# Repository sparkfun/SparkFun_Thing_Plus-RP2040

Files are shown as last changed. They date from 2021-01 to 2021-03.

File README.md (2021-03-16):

SparkFun Thing Plus RP2040
========================================

SparkFun Thing Plus RP2040 (https://www.sparkfun.com/products/17745)

[*SparkFun Thing Plus RP2040 (DEV-17745)*](https://www.sparkfun.com/products/17745)

The SparkFun Thing Plus - RP2040 is a low-cost, high performance board with flexible digital interfaces featuring the Raspberry Pi Foundation's RP2040 microcontroller. Besides the Thing Plus or *Feather* footprint (with 18 GPIO pins), the board also includes an SD card slot, 16MB (128Mbit) flash memory, a JST single cell battery connector (with a charging circuit and fuel gauge sensor), an addressable WS2812 RGB LED, JTAG PTH pins, four (4-40 screw) mounting holes, and our signature Qwiic connector.

The RP2040 is supported with both C/C++ and MicroPython cross-platform development environments, including easy access to runtime debugging. It has UF2 boot and floating-point routines baked into the chip. While the chip has a large amount of internal RAM, the board includes an additional 16MB of external QSPI flash memory to store program code.

Repository Contents
-------------------

* **/Documentation** - Data sheets, additional product information
* **/Hardware** - Eagle design files (.brd, .sch)

Documentation
--------------

* **[Hookup Guide](https://learn.sparkfun.com/tutorials/1527)** - Basic hookup guide for the Thing Plus RP2040
* **[Raspberry Pi RP2040 Datasheet](https://datasheets.raspberrypi.org/rp2040/rp2040_datasheet.pdf)** - Datasheet for the RP2040
* **[SparkFun Graphical Datasheets](https://github.com/sparkfun/Graphical_Datasheets)** - Graphical datasheets for various SparkFun products.

Product Versions
----------------
* [DEV-17745](https://www.sparkfun.com/products/17745) -  initial release

License Information
-------------------

This product is _**open source**_! 

Please review the LICENSE.md file for license information. 

If you have any questions or concerns on licensing, please contact technical support on our [SparkFun forums](https://forum.sparkfun.com/viewforum.php?f=152).

Distributed as-is; no warranty is given.

- Your friends at SparkFun.

_<COLLABORATION CREDIT>_

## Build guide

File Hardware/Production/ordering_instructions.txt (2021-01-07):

panel size, 107x201mm
PCB thickness, 1.6mm
number of layers, 4
soldermask color, Red
silkscreen color, White
oz copper, 1oz
finish, HASL lead free
stencils, none
pcs per panel, 12
min trace width, 0.1270mm / 0.0050in
min drill size, 0.2000mm / 0.0079in
filename to layer stackup 1/2/3/4: GTL, GL2, GL3, GBL

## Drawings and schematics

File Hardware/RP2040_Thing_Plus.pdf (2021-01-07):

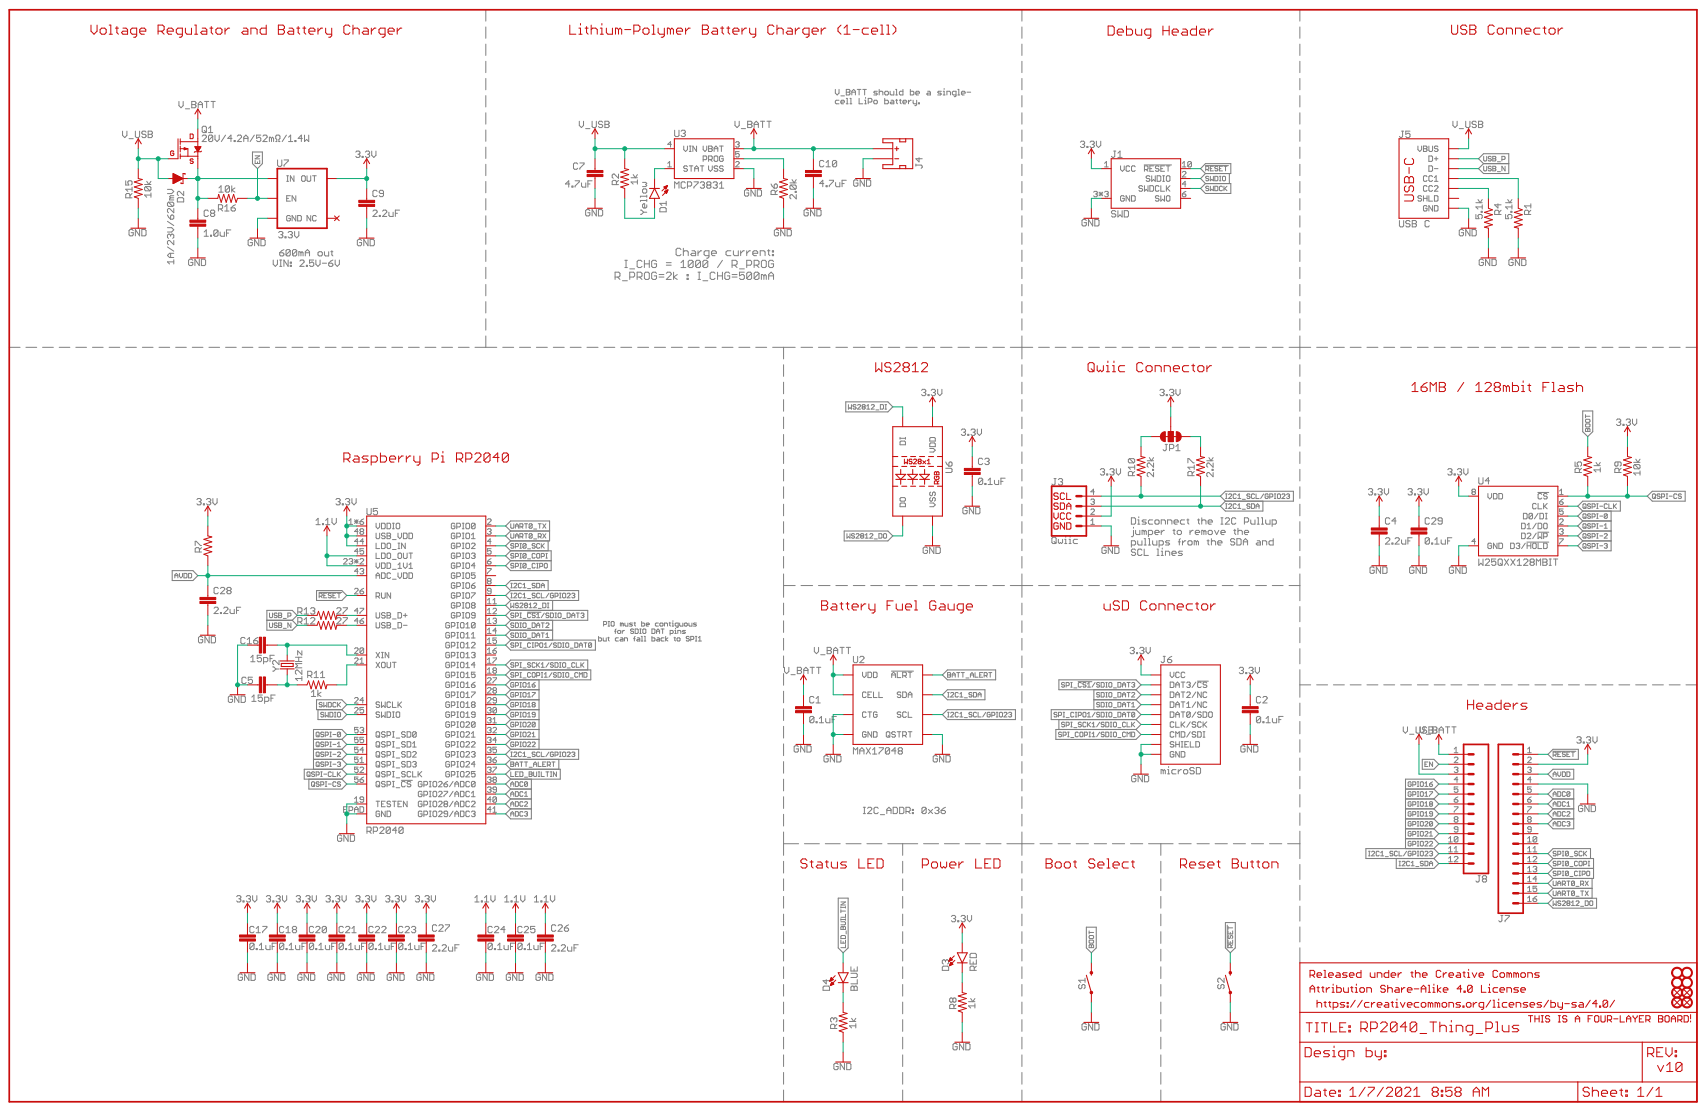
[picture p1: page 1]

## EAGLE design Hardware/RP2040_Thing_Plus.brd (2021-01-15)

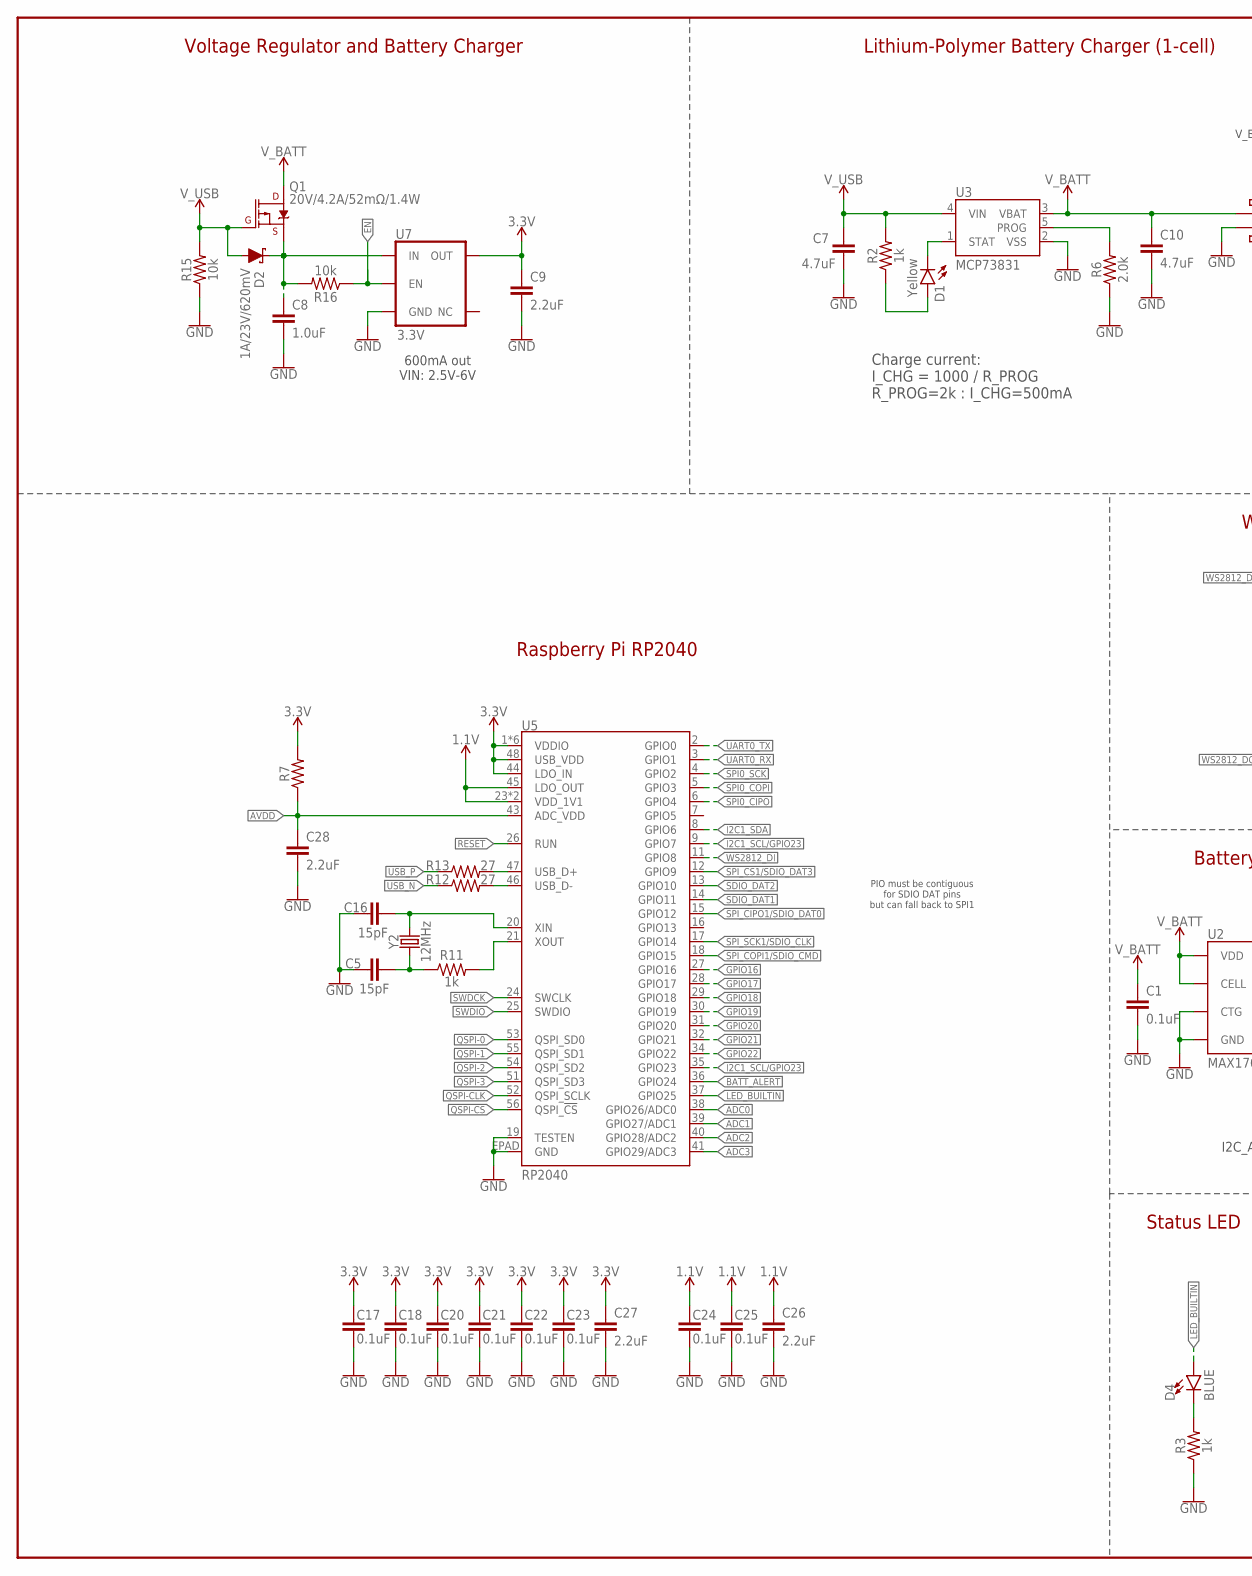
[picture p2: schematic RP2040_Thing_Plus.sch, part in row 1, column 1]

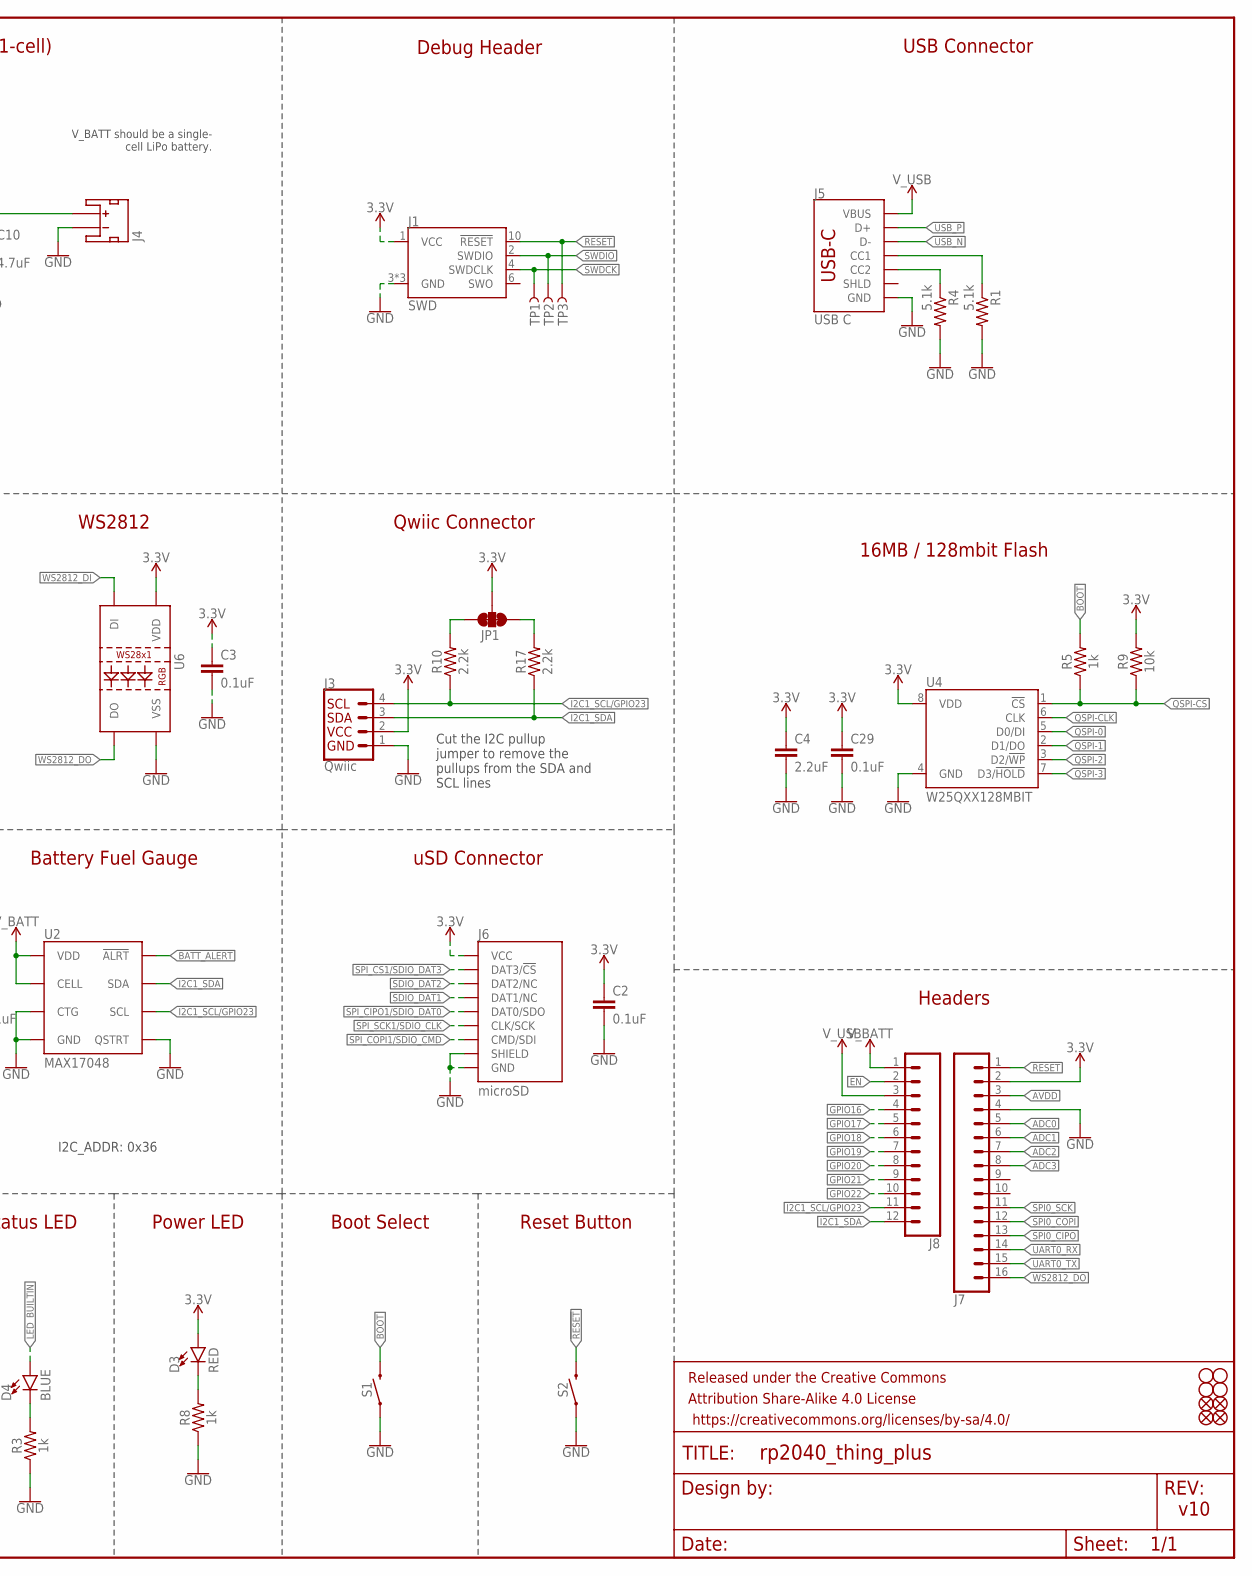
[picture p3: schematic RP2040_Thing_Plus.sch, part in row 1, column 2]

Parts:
C1, C2, C3, C17, C18, C20, C21, C22, C23, C24, C25, C29: 0.1uF; 0402-TIGHT
C4, C9, C26, C27, C28: 2.2uF; 0402-TIGHT
C5, C16: 15pF; 0402-TIGHT
C7, C10: 4.7uF; 0402-TIGHT
C8: 1.0uF; 0402-TIGHT
D1: Yellow; LED-0603
D2: 1A/23V/620mV; SOD-323
D3: RED; LED-0603
D4: BLUE; LED-0603
FD1, FD2, FD3, FD4: FIDUCIALUFIDUCIAL; FIDUCIAL-MICRO
FRAME1: FRAME-LEDGER; CREATIVE_COMMONS
H1, H2, H3, H4: STAND-OFF
J1: SWD; 2X5-PTH-1.27MM
J3: Qwiic; JST04_1MM_RA
J4: JST_2MM_MALE; JST-2-SMD
J5: USB C; USB-C-16P-4LAYER-ISOLATED
J6: microSD; MICRO-SD-SOCKET
J7: CONN_161X16_NO_SILK; 1X16_NO_SILK
J8: CONN_12NO_SILK; 1X12_NO_SILK
JP1: JUMPER-SMT_3_2-NC_TRACE_SILK; SMT-JUMPER_3_2-NC_TRACE_SILK
Q1: 20V/4.2A/52mΩ/1.4W; SOT23-3
R1, R4: 5.1k; 0402-TIGHT
R2, R3, R5, R8, R11: 1k; 0402-TIGHT
R6: 2.0k; 0603
R7: 200OHM-0402T-1/16W-1%; 0402-TIGHT
R9, R15, R16: 10k; 0402-TIGHT
R10, R17: 2.2k; 0402-TIGHT
R12, R13: 27; 0402-TIGHT
S1, S2: MOMENTARY-SWITCH-SPST-SMD-5.2MM-TALL; TACTILE_SWITCH_SMD_5.2MM
TP1, TP2, TP3: TEST-POINT3X4; PAD.03X.04
U2: MAX17048; DFN-8
U3: MCP73831; SOT23-5
U4: W25QXX128MBIT; WSON-8-6X5-SKINNY_CENTERPAD
U5: RP2040; QFN-56
U6: WS2812-2020
U7: 3.3V; SOT23-5
Y2: 12MHz; CRYSTAL-SMD-2X2.5MM

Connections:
1.1V: C24.1, C25.1, C26.1, U5.23 (VDD_1V1), U5.45 (LDO_OUT), U5.50 (VDD_1V1)
3.3V: C2.1, C3.1, C4.1, C9.1, C17.1, C18.1, C20.1, C21.1, C22.1, C23.1, C27.1, C29.1, D3.A, J1.1 (VCC), J3.2, J6.VCC, J7.2, JP1.2, R7.2, R9.2, U4.8 (VDD), U5.1 (VDDIO), U5.10 (VDDIO), U5.22 (VDDIO), U5.33 (VDDIO), U5.42 (VDDIO), U5.44 (LDO_IN), U5.48 (USB_VDD), U5.49 (VDDIO), U6.4 (VDD), U7.5 (OUT)
!RESET!: J1.10 (!RESET), J7.1, S2.3 (2), TP3.P$1, U5.26 (RUN)
ADC0: J7.5, U5.38 (GPIO26/ADC0)
ADC1: J7.6, U5.39 (GPIO27/ADC1)
ADC2: J7.7, U5.40 (GPIO28/ADC2)
ADC3: J7.8, U5.41 (GPIO29/ADC3)
AVDD: C28.1, J7.3, R7.1, U5.43 (ADC_VDD)
BATT_ALERT: U2.5 (!ALRT), U5.36 (GPIO24)
BOOT: R5.2, S1.3 (2)
EN: J8.2, R16.1, U7.3 (EN)
GND: C1.2, C2.2, C3.2, C4.2, C5.1, C7.2, C8.2, C9.2, C10.2, C16.1, C17.2, C18.2, C20.2, C21.2, C22.2, C23.2, C24.2, C25.2, C26.2, C27.2, C28.2, C29.2, J1.3 (GND), J1.5 (GND), J1.9 (GND), J3.1, J4.1 (-), J5.GND, J5.GND2 (GND), J6.CD1 (SHIELD), J6.GND, J6.GND1 (GND), J6.GND3 (GND), J7.4, R1.2, R3.1, R4.2, R6.1, R8.1, R15.1, S1.1, S2.1, U2.1 (CTG), U2.4 (GND), U2.6 (QSTRT), U2.9 (GND), U3.2 (VSS), U4.4 (GND), U5.19 (TESTEN), U5.EPAD (GND), U6.2 (VSS), U7.2 (GND)
GPIO16: J8.4, U5.27 (GPIO16)
GPIO17: J8.5, U5.28 (GPIO17)
GPIO18: J8.6, U5.29 (GPIO18)
GPIO19: J8.7, U5.30 (GPIO19)
GPIO20: J8.8, U5.31 (GPIO20)
GPIO21: J8.9, U5.32 (GPIO21)
GPIO22: J8.10, U5.34 (GPIO22)
I2C1_SCL/GPIO23: J3.4, J8.11, R10.1, U2.7 (SCL), U5.9 (GPIO7), U5.35 (GPIO23)
I2C1_SDA: J3.3, J8.12, R17.1, U2.8 (SDA), U5.8 (GPIO6)
LED_BUILTIN: D4.A, U5.37 (GPIO25)
unnamed: D4.C, R3.2
unnamed: JP1.3, R10.2
unnamed: JP1.1, R17.2
unnamed: R11.2, U5.21 (XOUT)
unnamed: C16.2, U5.20 (XIN), Y2.P3 (2)
unnamed: C5.2, R11.1, Y2.P1 (1)
unnamed: D3.C, R8.2
unnamed: D1.C, U3.1 (STAT)
unnamed: J5.A5 (CC1), R1.1
unnamed: J5.B5 (CC2), R4.1
unnamed: R6.2, U3.5 (PROG)
unnamed: C8.1, D2.C, Q1.2 (S), R16.2, U7.1 (IN)
unnamed: D1.A, R2.1
QSPI-0: U4.5 (D0/DI), U5.53 (QSPI_SD0)
QSPI-1: U4.2 (D1/DO), U5.55 (QSPI_SD1)
QSPI-2: U4.3 (D2/!WP!), U5.54 (QSPI_SD2)
QSPI-3: U4.7 (D3/!HOLD!), U5.51 (QSPI_SD3)
QSPI-CLK: U4.6 (CLK), U5.52 (QSPI_SCLK)
QSPI-CS: R5.1, R9.1, U4.1 (!CS!), U5.56 (QSPI_!CS!)
SDIO_DAT1: J6.DAT1 (DAT1/NC), U5.14 (GPIO11)
SDIO_DAT2: J6.DAT2 (DAT2/NC), U5.13 (GPIO10)
SPI0_CIPO: J7.13, U5.6 (GPIO4)
SPI0_COPI: J7.12, U5.5 (GPIO3)
SPI0_SCK: J7.11, U5.4 (GPIO2)
SPI_!CS1!/SDIO_DAT3: J6.CS/DAT3 (DAT3/!CS!), U5.12 (GPIO9)
SPI_CIPO1/SDIO_DAT0: J6.DO/DAT0 (DAT0/SDO), U5.15 (GPIO12)
SPI_COPI1/SDIO_CMD: J6.DI/CMD (CMD/SDI), U5.18 (GPIO15)
SPI_SCK1/SDIO_CLK: J6.SCLK (CLK/SCK), U5.17 (GPIO14)
SWDCK: J1.4 (SWDCLK), TP1.P$1, U5.24 (SWCLK)
SWDIO: J1.2 (SWDIO), TP2.P$1, U5.25 (SWDIO)
UART0_RX: J7.14, U5.3 (GPIO1)
UART0_TX: J7.15, U5.2 (GPIO0)
USB_F_N: R12.2, U5.46 (USB_D-)
USB_F_P: R13.2, U5.47 (USB_D+)
USB_N: J5.A7 (D-), J5.B7 (D-), R12.1
USB_P: J5.A6 (D+), J5.B6 (D+), R13.1
V_BATT: C1.1, C10.1, J4.2 (+), J8.1, Q1.3 (D), U2.2 (CELL), U2.3 (VDD), U3.3 (VBAT)
V_USB: C7.1, D2.A, J5.VBUS1 (VBUS), J5.VBUS2 (VBUS), J8.3, Q1.1 (G), R2.2, R15.2, U3.4 (VIN)
WS2812_DI: U5.11 (GPIO8), U6.3 (DI)
WS2812_DO: J7.16, U6.1 (DO)

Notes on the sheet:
V_BATT should be a single- cell LiPo battery.
Charge current: I_CHG = 1000 / R_PROG R_PROG=2k : I_CHG=500mA
Voltage Regulator and Battery Charger
Lithium-Polymer Battery Charger (1-cell)
600mA out VIN: 2.5V-6V
Reset Button
Status LED
Headers
v10
Qwiic Connector
USB Connector
Cut the I2C pullup jumper to remove the pullups from the SDA and SCL lines
Raspberry Pi RP2040
PIO must be contiguous for SDIO DAT pins but can fall back to SPI1
16MB / 128mbit Flash
uSD Connector
Battery Fuel Gauge
WS2812
I2C_ADDR: 0x36
Boot Select
Debug Header
Power LED

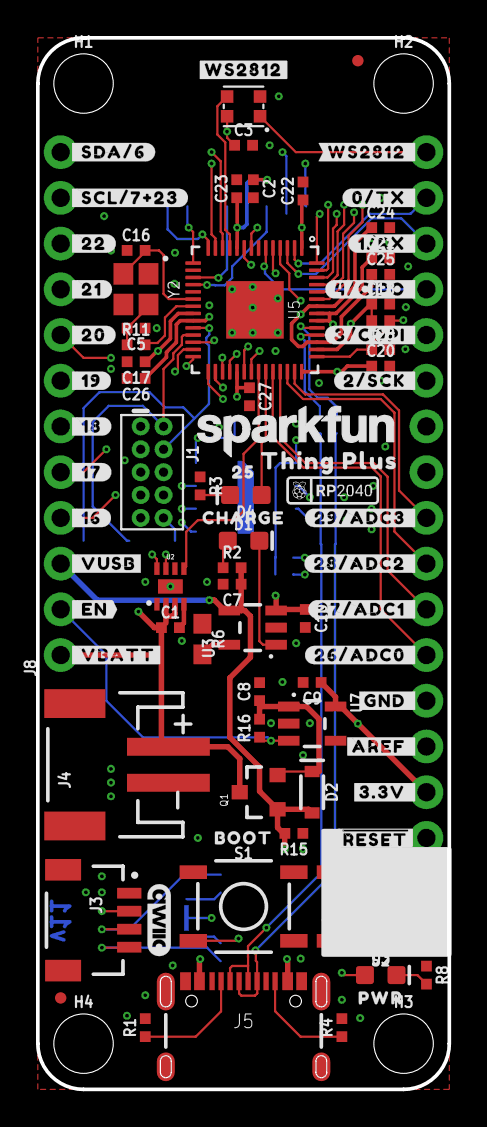
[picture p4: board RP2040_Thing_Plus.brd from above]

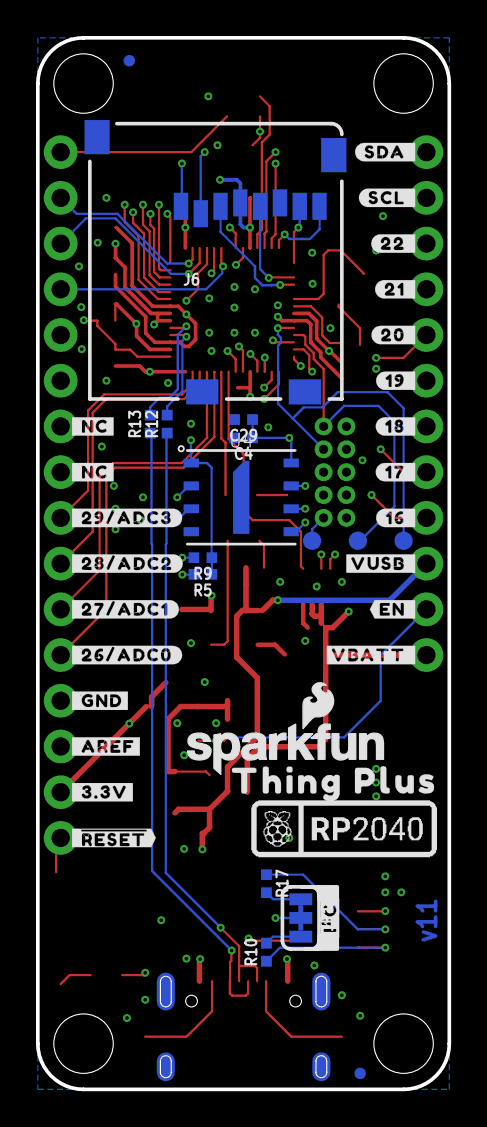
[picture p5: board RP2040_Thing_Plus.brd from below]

Board: 4 copper layers, 22.9 x 58.4 mm, 134 parts (42 on the bottom side), 62 nets.

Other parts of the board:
U$1: #_16#0
U$2: #_17#0
U$3: #_18#0
U$4: #_19#0
U$5: #_20#0
U$6: #_21#0
U$7: #_22#0
U$8: #_SCL#7#23#0
U$9: #_SDA#6#0
U$10: #WS2812_#0
U$11: #0#TX_#0
U$12: #1#RX_#0
U$13: #4#CIPO_#0
U$14: #3#COPI_#0
U$15: #2#SCK_#0
U$16: PWR0
U$17: #I�C#0
U$18: #29#ADC3_#0
U$19: #28#ADC2_#0
U$20: #27#ADC1_#0
U$21: #26#ADC0_#0
U$22: #_VUSB#0
U$23: #_EN#0
U$24: #_VBATT#0
U$25: #GND_#0
U$26: #AREF_#0
U$27: #3#3V_#0
U$28: ##RESET##0
U$29: RP2040_10
U$30: RP2040_20
U$31: ORDERING_INSTRUCTIONS
U$32: SFE_LOGO_NAME_FLAME_.1
U$33: #SCL_#0
U$34: #SDA_#0
U$35: #_#RESET##0
U$36: #_3#3V#0
U$37: #_AREF#0
U$38: #_GND#0
U$39: #_26#ADC0#0
U$40: #_27#ADC1#0
U$41: #_28#ADC2#0
U$42: #_29#ADC3#0
U$44: THING_PLUS0
U$45: SFE_LOGO_NAME_.1
U$47: THING_PLUS_0
U$54: 250
U$55: CHARGE0
U$56: BOOT0
U$57: #22_#0
U$58: #21_#0
U$59: #20_#0
U$60: #WS2812#0
U$61: #19_#0
U$62: #18_#0
U$63: #17_#0
U$64: QWIIC_4MM
U$65: #16_#0
U$66: #VUSB_#0
U$67: #EN_#0
U$68: #VBATT_#0
U$69, U$70: #_NC#0

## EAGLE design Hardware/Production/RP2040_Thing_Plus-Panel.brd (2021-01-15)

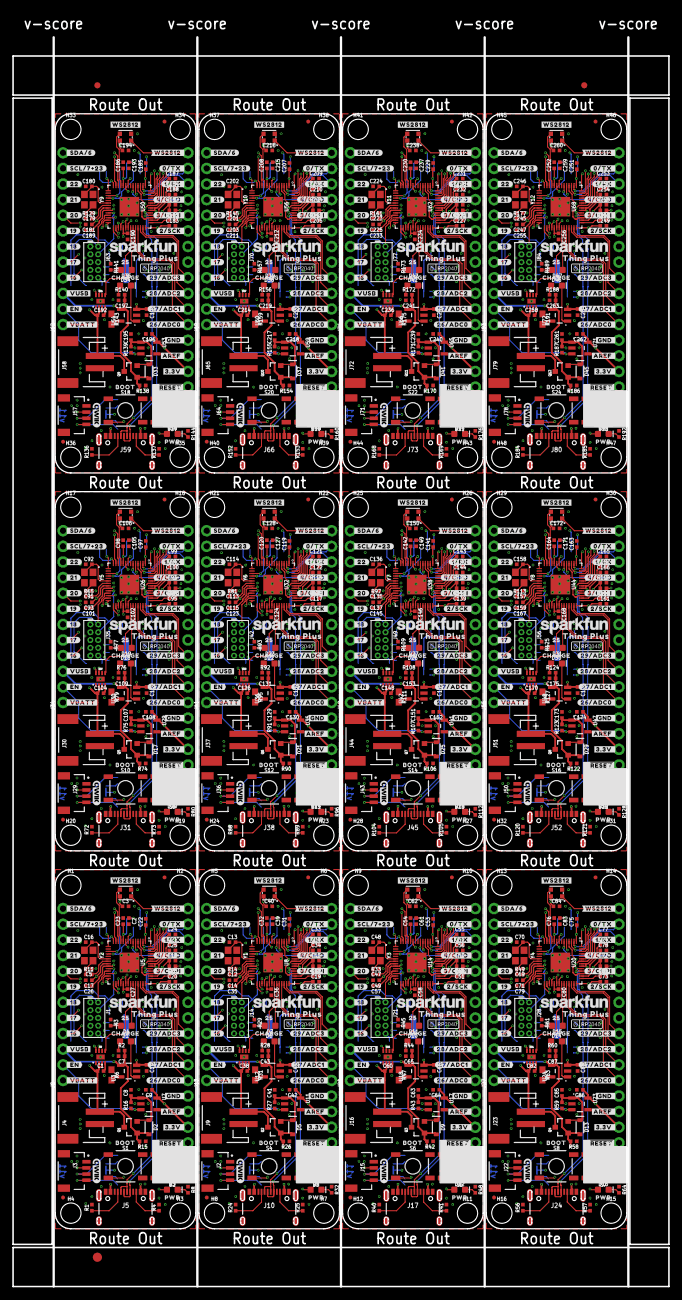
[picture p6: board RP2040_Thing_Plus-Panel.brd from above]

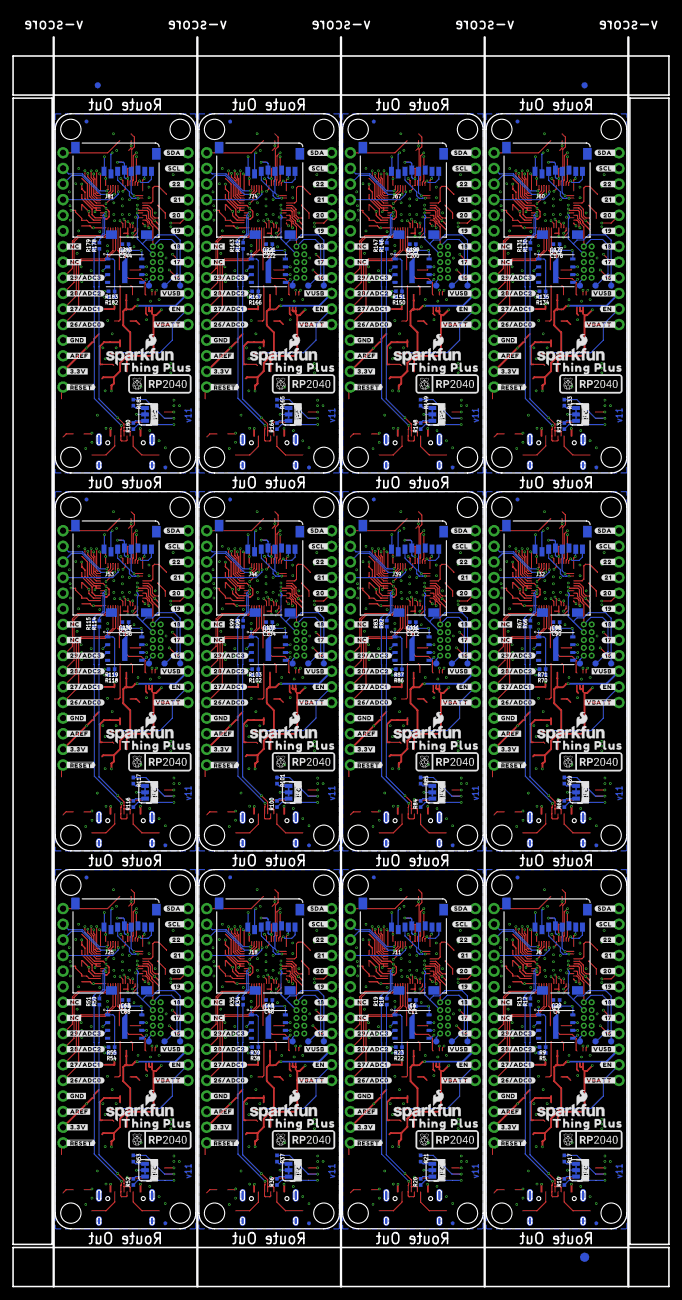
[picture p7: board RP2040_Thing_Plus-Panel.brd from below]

Board: 4 copper layers, 106.7 x 203.2 mm, 1590 parts (507 on the bottom side), 744 nets.

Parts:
C1, C2, C3, C6, C14, C15, C17, C18, C19, C20, C21, C22, C23, C24, C25, C29, C30, C31, C32, C33, C34, C38, C39, C40, C45, C49, C50, C51, C52, C53, C54, C55, C56, C60, C61, C62, C67, C71, C72, C73, C74, C75, C76, C77, C78, C82, C83, C84, C89, C93, C94, C95, C96, C97, C98, C99, C100, C104, C105, C106, C111, C115, C116, C117, C118, C119, C120, C121, C122, C126, C127, C128, C133, C137, C138, C139, C140, C141, C142, C143, C144, C148, C149, C150, C155, C159, C160, C161, C162, C163, C164, C165, C166, C170, C171, C172, C177, C181, C182, C183, C184, C185, C186, C187, C188, C192, C193, C194, C199, C203, C204, C205, C206, C207, C208, C209, C210, C214, C215, C216, C221, C225, C226, C227, C228, C229, C230, C231, C232, C236, C237, C238, C243, C247, C248, C249, C250, C251, C252, C253, C254, C258, C259, C260: 0.1uF; 0402-TIGHT
C4, C9, C11, C26, C27, C28, C35, C36, C37, C42, C46, C57, C58, C59, C64, C68, C79, C80, C81, C86, C90, C101, C102, C103, C108, C112, C123, C124, C125, C130, C134, C145, C146, C147, C152, C156, C167, C168, C169, C174, C178, C189, C190, C191, C196, C200, C211, C212, C213, C218, C222, C233, C234, C235, C240, C244, C255, C256, C257, C262: 2.2uF; 0402-TIGHT
C5, C12, C13, C16, C47, C48, C69, C70, C91, C92, C113, C114, C135, C136, C157, C158, C179, C180, C201, C202, C223, C224, C245, C246: 15pF; 0402-TIGHT
C7, C10, C43, C44, C65, C66, C87, C88, C109, C110, C131, C132, C153, C154, C175, C176, C197, C198, C219, C220, C241, C242, C263, C264: 4.7uF; 0402-TIGHT
C8, C41, C63, C85, C107, C129, C151, C173, C195, C217, C239, C261: 1.0uF; 0402-TIGHT
D1, D6, D10, D14, D18, D22, D26, D30, D34, D38, D42, D46: Yellow; LED-0603
D2, D5, D9, D13, D17, D21, D25, D29, D33, D37, D41, D45: 1A/23V/620mV; SOD-323
D3, D8, D12, D16, D20, D24, D28, D32, D36, D40, D44, D48: RED; LED-0603
D4, D7, D11, D15, D19, D23, D27, D31, D35, D39, D43, D47: BLUE; LED-0603
E$1, E$2, E$3, E$4: FIDUCIAL-1X2
E$5, E$6: FIDUCIAL-1.5X3
FD1, FD2, FD3, FD4, FD5, FD6, FD7, FD8, FD9, FD10, FD11, FD12, FD13, FD14, FD15, FD16, FD17, FD18, FD19, FD20, FD21, FD22, FD23, FD24, FD25, FD26, FD27, FD28, FD29, FD30, FD31, FD32, FD33, FD34, FD35, FD36, FD37, FD38, FD39, FD40, FD41, FD42, FD43, FD44, FD45, FD46, FD47, FD48: FIDUCIALUFIDUCIAL; FIDUCIAL-MICRO
H1, H2, H3, H4, H5, H6, H7, H8, H9, H10, H11, H12, H13, H14, H15, H16, H17, H18, H19, H20, H21, H22, H23, H24, H25, H26, H27, H28, H29, H30, H31, H32, H33, H34, H35, H36, H37, H38, H39, H40, H41, H42, H43, H44, H45, H46, H47, H48: STAND-OFF
J1, J14, J21, J28, J35, J42, J49, J56, J63, J70, J77, J84: SWD; 2X5-PTH-1.27MM
J2, J3, J15, J22, J29, J36, J43, J50, J57, J64, J71, J78: Qwiic; JST04_1MM_RA
J4, J9, J16, J23, J30, J37, J44, J51, J58, J65, J72, J79: JST-2-SMD
J5, J10, J17, J24, J31, J38, J45, J52, J59, J66, J73, J80: USB C; USB-C-16P-4LAYER-ISOLATED
J6, J11, J18, J25, J32, J39, J46, J53, J60, J67, J74, J81: microSD; MICRO-SD-SOCKET
J7, J12, J19, J26, J33, J40, J47, J54, J61, J68, J75, J82: 1X16_NO_SILK
J8, J13, J20, J27, J34, J41, J48, J55, J62, J69, J76, J83: 1X12_NO_SILK
JP1, JP2, JP3, JP4, JP5, JP6, JP7, JP8, JP9, JP10, JP11, JP12: JUMPER-SMT_3_2-NC_TRACE_SILK; SMT-JUMPER_3_2-NC_TRACE_SILK
Q1, Q2, Q3, Q4, Q5, Q6, Q7, Q8, Q9, Q10, Q11, Q12: 20V/4.2A/52mΩ/1.4W; SOT23-3
R1, R4, R24, R25, R40, R41, R56, R57, R72, R73, R88, R89, R104, R105, R120, R121, R136, R137, R152, R153, R168, R169, R184, R185: 5.1k; 0402-TIGHT
R2, R3, R5, R8, R11, R14, R22, R28, R29, R32, R33, R38, R44, R45, R48, R49, R54, R60, R61, R64, R65, R70, R76, R77, R80, R81, R86, R92, R93, R96, R97, R102, R108, R109, R112, R113, R118, R124, R125, R128, R129, R134, R140, R141, R144, R145, R150, R156, R157, R160, R161, R166, R172, R173, R176, R177, R182, R188, R189, R192: 1k; 0402-TIGHT
R6, R31, R47, R63, R79, R95, R111, R127, R143, R159, R175, R191: 2.0k; 0603
R7, R30, R46, R62, R78, R94, R110, R126, R142, R158, R174, R190: 200OHM-0402T-1/16W-1%; 0402-TIGHT
R9, R15, R16, R23, R26, R27, R39, R42, R43, R55, R58, R59, R71, R74, R75, R87, R90, R91, R103, R106, R107, R119, R122, R123, R135, R138, R139, R151, R154, R155, R167, R170, R171, R183, R186, R187: 10k; 0402-TIGHT
R10, R17, R20, R21, R36, R37, R52, R53, R68, R69, R84, R85, R100, R101, R116, R117, R132, R133, R148, R149, R164, R165, R180, R181: 2.2k; 0402-TIGHT
R12, R13, R18, R19, R34, R35, R50, R51, R66, R67, R82, R83, R98, R99, R114, R115, R130, R131, R146, R147, R162, R163, R178, R179: 27; 0402-TIGHT
S1, S2, S3, S4, S5, S6, S7, S8, S9, S10, S11, S12, S13, S14, S15, S16, S17, S18, S19, S20, S21, S22, S23, S24: MOMENTARY-SWITCH-SPST-SMD-5.2MM-TALL; TACTILE_SWITCH_SMD_5.2MM
TP1, TP2, TP3, TP4, TP5, TP6, TP7, TP8, TP9, TP10, TP11, TP12, TP13, TP14, TP15, TP16, TP17, TP18, TP19, TP20, TP21, TP22, TP23, TP24, TP25, TP26, TP27, TP28, TP29, TP30, TP31, TP32, TP33, TP34, TP35, TP36: PAD.03X.04
U1, U4, U13, U19, U25, U31, U37, U43, U49, U55, U61, U67: W25QXX128MBIT; WSON-8-6X5-SKINNY_CENTERPAD
U2, U9, U15, U21, U27, U33, U39, U45, U51, U57, U63, U69: MAX17048; DFN-8
U3, U12, U18, U24, U30, U36, U42, U48, U54, U60, U66, U72: MCP73831; SOT23-5
U5, U8, U14, U20, U26, U32, U38, U44, U50, U56, U62, U68: RP2040; QFN-56
U6, U10, U16, U22, U28, U34, U40, U46, U52, U58, U64, U70: WS2812-2020
U7, U11, U17, U23, U29, U35, U41, U47, U53, U59, U65, U71: 3.3V; SOT23-5
U$1, U$31, U$123, U$184, U$245, U$306, U$367, U$428, U$489, U$550, U$611, U$672: #_16#0
U$2, U$43, U$124, U$185, U$246, U$307, U$368, U$429, U$490, U$551, U$612, U$673: #_17#0
U$3, U$46, U$125, U$186, U$247, U$308, U$369, U$430, U$491, U$552, U$613, U$674: #_18#0
U$4, U$48, U$126, U$187, U$248, U$309, U$370, U$431, U$492, U$553, U$614, U$675: #_19#0
U$5, U$49, U$127, U$188, U$249, U$310, U$371, U$432, U$493, U$554, U$615, U$676: #_20#0
U$6, U$50, U$128, U$189, U$250, U$311, U$372, U$433, U$494, U$555, U$616, U$677: #_21#0
U$7, U$51, U$129, U$190, U$251, U$312, U$373, U$434, U$495, U$556, U$617, U$678: #_22#0
U$8, U$75, U$136, U$197, U$258, U$319, U$380, U$441, U$502, U$563, U$624, U$685: #_SCL#7#23#0
U$9, U$76, U$137, U$198, U$259, U$320, U$381, U$442, U$503, U$564, U$625, U$686: #_SDA#6#0
U$10, U$52, U$130, U$191, U$252, U$313, U$374, U$435, U$496, U$557, U$618, U$679: #WS2812_#0
U$11, U$53, U$131, U$192, U$253, U$314, U$375, U$436, U$497, U$558, U$619, U$680: #0#TX_#0
U$12, U$71, U$132, U$193, U$254, U$315, U$376, U$437, U$498, U$559, U$620, U$681: #1#RX_#0
U$13, U$72, U$133, U$194, U$255, U$316, U$377, U$438, U$499, U$560, U$621, U$682: #4#CIPO_#0
U$14, U$73, U$134, U$195, U$256, U$317, U$378, U$439, U$500, U$561, U$622, U$683: #3#COPI_#0
U$15, U$74, U$135, U$196, U$257, U$318, U$379, U$440, U$501, U$562, U$623, U$684: #2#SCK_#0
U$16, U$116, U$177, U$238, U$299, U$360, U$421, U$482, U$543, U$604, U$665, U$726: PWR0
U$17, U$117, U$178, U$239, U$300, U$361, U$422, U$483, U$544, U$605, U$666, U$727: #I�C#0
U$18, U$77, U$138, U$199, U$260, U$321, U$382, U$443, U$504, U$565, U$626, U$687: #29#ADC3_#0
U$19, U$78, U$139, U$200, U$261, U$322, U$383, U$444, U$505, U$566, U$627, U$688: #28#ADC2_#0
U$20, U$79, U$140, U$201, U$262, U$323, U$384, U$445, U$506, U$567, U$628, U$689: #27#ADC1_#0
U$21, U$80, U$141, U$202, U$263, U$324, U$385, U$446, U$507, U$568, U$629, U$690: #26#ADC0_#0
U$22, U$81, U$142, U$203, U$264, U$325, U$386, U$447, U$508, U$569, U$630, U$691: #_VUSB#0
U$23, U$82, U$143, U$204, U$265, U$326, U$387, U$448, U$509, U$570, U$631, U$692: #_EN#0
U$24, U$83, U$144, U$205, U$266, U$327, U$388, U$449, U$510, U$571, U$632, U$693: #_VBATT#0
U$25, U$84, U$145, U$206, U$267, U$328, U$389, U$450, U$511, U$572, U$633, U$694: #GND_#0
U$26, U$85, U$146, U$207, U$268, U$329, U$390, U$451, U$512, U$573, U$634, U$695: #AREF_#0
U$27, U$86, U$147, U$208, U$269, U$330, U$391, U$452, U$513, U$574, U$635, U$696: #3#3V_#0
U$28, U$87, U$148, U$209, U$270, U$331, U$392, U$453, U$514, U$575, U$636, U$697: ##RESET##0
U$29, U$122, U$183, U$244, U$305, U$366, U$427, U$488, U$549, U$610, U$671, U$732: RP2040_10
U$30, U$121, U$182, U$243, U$304, U$365, U$426, U$487, U$548, U$609, U$670, U$731: RP2040_20
U$32, U$90, U$151, U$212, U$273, U$334, U$395, U$456, U$517, U$578, U$639, U$700: SFE_LOGO_NAME_FLAME_.1
U$33, U$104, U$165, U$226, U$287, U$348, U$409, U$470, U$531, U$592, U$653, U$714: #SCL_#0
U$34, U$105, U$166, U$227, U$288, U$349, U$410, U$471, U$532, U$593, U$654, U$715: #SDA_#0
U$35, U$106, U$167, U$228, U$289, U$350, U$411, U$472, U$533, U$594, U$655, U$716: #_#RESET##0
U$36, U$107, U$168, U$229, U$290, U$351, U$412, U$473, U$534, U$595, U$656, U$717: #_3#3V#0
U$37, U$108, U$169, U$230, U$291, U$352, U$413, U$474, U$535, U$596, U$657, U$718: #_AREF#0
U$38, U$109, U$170, U$231, U$292, U$353, U$414, U$475, U$536, U$597, U$658, U$719: #_GND#0
U$39, U$110, U$171, U$232, U$293, U$354, U$415, U$476, U$537, U$598, U$659, U$720: #_26#ADC0#0
U$40, U$111, U$172, U$233, U$294, U$355, U$416, U$477, U$538, U$599, U$660, U$721: #_27#ADC1#0
U$41, U$112, U$173, U$234, U$295, U$356, U$417, U$478, U$539, U$600, U$661, U$722: #_28#ADC2#0
U$42, U$113, U$174, U$235, U$296, U$357, U$418, U$479, U$540, U$601, U$662, U$723: #_29#ADC3#0
U$44, U$120, U$181, U$242, U$303, U$364, U$425, U$486, U$547, U$608, U$669, U$730: THING_PLUS0
U$45, U$118, U$179, U$240, U$301, U$362, U$423, U$484, U$545, U$606, U$667, U$728: SFE_LOGO_NAME_.1
U$47, U$119, U$180, U$241, U$302, U$363, U$424, U$485, U$546, U$607, U$668, U$729: THING_PLUS_0
U$54, U$91, U$152, U$213, U$274, U$335, U$396, U$457, U$518, U$579, U$640, U$701: 250
U$55, U$92, U$153, U$214, U$275, U$336, U$397, U$458, U$519, U$580, U$641, U$702: CHARGE0
U$56, U$93, U$154, U$215, U$276, U$337, U$398, U$459, U$520, U$581, U$642, U$703: BOOT0
U$57, U$94, U$155, U$216, U$277, U$338, U$399, U$460, U$521, U$582, U$643, U$704: #22_#0
U$58, U$95, U$156, U$217, U$278, U$339, U$400, U$461, U$522, U$583, U$644, U$705: #21_#0
U$59, U$96, U$157, U$218, U$279, U$340, U$401, U$462, U$523, U$584, U$645, U$706: #20_#0
U$60, U$88, U$149, U$210, U$271, U$332, U$393, U$454, U$515, U$576, U$637, U$698: #WS2812#0
U$61, U$97, U$158, U$219, U$280, U$341, U$402, U$463, U$524, U$585, U$646, U$707: #19_#0
U$62, U$98, U$159, U$220, U$281, U$342, U$403, U$464, U$525, U$586, U$647, U$708: #18_#0
U$63, U$99, U$160, U$221, U$282, U$343, U$404, U$465, U$526, U$587, U$648, U$709: #17_#0
U$64, U$89, U$150, U$211, U$272, U$333, U$394, U$455, U$516, U$577, U$638, U$699: QWIIC_4MM
U$65, U$100, U$161, U$222, U$283, U$344, U$405, U$466, U$527, U$588, U$649, U$710: #16_#0
U$66, U$101, U$162, U$223, U$284, U$345, U$406, U$467, U$528, U$589, U$650, U$711: #VUSB_#0
U$67, U$102, U$163, U$224, U$285, U$346, U$407, U$468, U$529, U$590, U$651, U$712: #EN_#0
U$68, U$103, U$164, U$225, U$286, U$347, U$408, U$469, U$530, U$591, U$652, U$713: #VBATT_#0
U$69, U$70, U$114, U$115, U$175, U$176, U$236, U$237, U$297, U$298, U$358, U$359, U$419, U$420, U$480, U$481, U$541, U$542, U$602, U$603, U$663, U$664, U$724, U$725: #_NC#0
Y1, Y2, Y3, Y4, Y5, Y6, Y7, Y8, Y9, Y10, Y11, Y12: 12MHz; CRYSTAL-SMD-2X2.5MM

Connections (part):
1.1V: C24.1, C25.1, C26.1, U5.23, U5.45, U5.50
1.1V1: C33.1, C34.1, C35.1, U8.23, U8.45, U8.50
1.1V2: C55.1, C56.1, C57.1, U14.23, U14.45, U14.50
1.1V3: C77.1, C78.1, C79.1, U20.23, U20.45, U20.50
1.1V4: C99.1, C100.1, C101.1, U26.23, U26.45, U26.50
1.1V5: C121.1, C122.1, C123.1, U32.23, U32.45, U32.50
1.1V6: C143.1, C144.1, C145.1, U38.23, U38.45, U38.50
1.1V7: C165.1, C166.1, C167.1, U44.23, U44.45, U44.50
1.1V8: C187.1, C188.1, C189.1, U50.23, U50.45, U50.50
1.1V9: C209.1, C210.1, C211.1, U56.23, U56.45, U56.50
1.1V10: C231.1, C232.1, C233.1, U62.23, U62.45, U62.50
1.1V11: C253.1, C254.1, C255.1, U68.23, U68.45, U68.50
3.3V: C2.1, C3.1, C4.1, C9.1, C17.1, C18.1, C20.1, C21.1, C22.1, C23.1, C27.1, C29.1, D3.A, J1.1, J3.2, J6.VCC, J7.2, JP1.2, R7.2, R9.2, U4.8, U5.1, U5.10, U5.22, U5.33, U5.42, U5.44, U5.48, U5.49, U6.4, U7.5
3.3V1: C6.1, C11.1, C14.1, C15.1, C19.1, C30.1, C31.1, C32.1, C36.1, C39.1, C40.1, C42.1, D8.A, J2.2, J11.VCC, J12.2, J14.1, JP2.2, R23.2, R30.2, U1.8, U8.1, U8.10, U8.22, U8.33, U8.42, U8.44, U8.48, U8.49, U10.4, U11.5
3.3V2: C45.1, C46.1, C49.1, C50.1, C51.1, C52.1, C53.1, C54.1, C58.1, C61.1, C62.1, C64.1, D12.A, J15.2, J18.VCC, J19.2, J21.1, JP3.2, R39.2, R46.2, U13.8, U14.1, U14.10, U14.22, U14.33, U14.42, U14.44, U14.48, U14.49, U16.4, U17.5
3.3V3: C67.1, C68.1, C71.1, C72.1, C73.1, C74.1, C75.1, C76.1, C80.1, C83.1, C84.1, C86.1, D16.A, J22.2, J25.VCC, J26.2, J28.1, JP4.2, R55.2, R62.2, U19.8, U20.1, U20.10, U20.22, U20.33, U20.42, U20.44, U20.48, U20.49, U22.4, U23.5
3.3V4: C89.1, C90.1, C93.1, C94.1, C95.1, C96.1, C97.1, C98.1, C102.1, C105.1, C106.1, C108.1, D20.A, J29.2, J32.VCC, J33.2, J35.1, JP5.2, R71.2, R78.2, U25.8, U26.1, U26.10, U26.22, U26.33, U26.42, U26.44, U26.48, U26.49, U28.4, U29.5
3.3V5: C111.1, C112.1, C115.1, C116.1, C117.1, C118.1, C119.1, C120.1, C124.1, C127.1, C128.1, C130.1, D24.A, J36.2, J39.VCC, J40.2, J42.1, JP6.2, R87.2, R94.2, U31.8, U32.1, U32.10, U32.22, U32.33, U32.42, U32.44, U32.48, U32.49, U34.4, U35.5
3.3V6: C133.1, C134.1, C137.1, C138.1, C139.1, C140.1, C141.1, C142.1, C146.1, C149.1, C150.1, C152.1, D28.A, J43.2, J46.VCC, J47.2, J49.1, JP7.2, R103.2, R110.2, U37.8, U38.1, U38.10, U38.22, U38.33, U38.42, U38.44, U38.48, U38.49, U40.4, U41.5
3.3V7: C155.1, C156.1, C159.1, C160.1, C161.1, C162.1, C163.1, C164.1, C168.1, C171.1, C172.1, C174.1, D32.A, J50.2, J53.VCC, J54.2, J56.1, JP8.2, R119.2, R126.2, U43.8, U44.1, U44.10, U44.22, U44.33, U44.42, U44.44, U44.48, U44.49, U46.4, U47.5
3.3V8: C177.1, C178.1, C181.1, C182.1, C183.1, C184.1, C185.1, C186.1, C190.1, C193.1, C194.1, C196.1, D36.A, J57.2, J60.VCC, J61.2, J63.1, JP9.2, R135.2, R142.2, U49.8, U50.1, U50.10, U50.22, U50.33, U50.42, U50.44, U50.48, U50.49, U52.4, U53.5
3.3V9: C199.1, C200.1, C203.1, C204.1, C205.1, C206.1, C207.1, C208.1, C212.1, C215.1, C216.1, C218.1, D40.A, J64.2, J67.VCC, J68.2, J70.1, JP10.2, R151.2, R158.2, U55.8, U56.1, U56.10, U56.22, U56.33, U56.42, U56.44, U56.48, U56.49, U58.4, U59.5
3.3V10: C221.1, C222.1, C225.1, C226.1, C227.1, C228.1, C229.1, C230.1, C234.1, C237.1, C238.1, C240.1, D44.A, J71.2, J74.VCC, J75.2, J77.1, JP11.2, R167.2, R174.2, U61.8, U62.1, U62.10, U62.22, U62.33, U62.42, U62.44, U62.48, U62.49, U64.4, U65.5
3.3V11: C243.1, C244.1, C247.1, C248.1, C249.1, C250.1, C251.1, C252.1, C256.1, C259.1, C260.1, C262.1, D48.A, J78.2, J81.VCC, J82.2, J84.1, JP12.2, R183.2, R190.2, U67.8, U68.1, U68.10, U68.22, U68.33, U68.42, U68.44, U68.48, U68.49, U70.4, U71.5
!RESET!: J1.10, J7.1, S2.3, TP3.P$1, U5.26
!RESET!1: J12.1, J14.10, S3.3, TP6.P$1, U8.26
!RESET!2: J19.1, J21.10, S5.3, TP9.P$1, U14.26
!RESET!3: J26.1, J28.10, S7.3, TP12.P$1, U20.26
!RESET!4: J33.1, J35.10, S9.3, TP15.P$1, U26.26
!RESET!5: J40.1, J42.10, S11.3, TP18.P$1, U32.26
!RESET!6: J47.1, J49.10, S13.3, TP21.P$1, U38.26
!RESET!7: J54.1, J56.10, S15.3, TP24.P$1, U44.26
!RESET!8: J61.1, J63.10, S17.3, TP27.P$1, U50.26
!RESET!9: J68.1, J70.10, S19.3, TP30.P$1, U56.26
!RESET!10: J75.1, J77.10, S21.3, TP33.P$1, U62.26
!RESET!11: J82.1, J84.10, S23.3, TP36.P$1, U68.26
ADC0: J7.5, U5.38
ADC1: J7.6, U5.39
ADC2: J7.7, U5.40
ADC3: J7.8, U5.41
ADC4: J12.8, U8.41
ADC5: J12.5, U8.38
ADC6: J12.6, U8.39
ADC7: J12.7, U8.40
ADC8: J19.8, U14.41
ADC9: J19.5, U14.38
ADC10: J19.6, U14.39
ADC11: J19.7, U14.40
ADC12: J26.8, U20.41
ADC13: J26.5, U20.38
ADC14: J26.6, U20.39
ADC15: J26.7, U20.40
ADC16: J33.8, U26.41
ADC17: J33.5, U26.38
ADC18: J33.6, U26.39
ADC19: J33.7, U26.40
ADC20: J40.8, U32.41
ADC21: J40.5, U32.38
ADC22: J40.6, U32.39
ADC23: J40.7, U32.40
ADC24: J47.8, U38.41
ADC25: J47.5, U38.38
ADC26: J47.6, U38.39
ADC27: J47.7, U38.40
ADC28: J54.8, U44.41
ADC29: J54.5, U44.38
ADC30: J54.6, U44.39
ADC31: J54.7, U44.40
ADC32: J61.8, U50.41
ADC33: J61.5, U50.38
ADC34: J61.6, U50.39
ADC35: J61.7, U50.40
ADC36: J68.8, U56.41
ADC37: J68.5, U56.38
ADC38: J68.6, U56.39
ADC39: J68.7, U56.40
ADC40: J75.8, U62.41
ADC41: J75.5, U62.38
ADC42: J75.6, U62.39
ADC43: J75.7, U62.40
ADC44: J82.8, U68.41
ADC45: J82.5, U68.38
ADC46: J82.6, U68.39
ADC47: J82.7, U68.40
AVDD: C28.1, J7.3, R7.1, U5.43
AVDD1: C37.1, J12.3, R30.1, U8.43
AVDD2: C59.1, J19.3, R46.1, U14.43
AVDD3: C81.1, J26.3, R62.1, U20.43
AVDD4: C103.1, J33.3, R78.1, U26.43
AVDD5: C125.1, J40.3, R94.1, U32.43
AVDD6: C147.1, J47.3, R110.1, U38.43
AVDD7: C169.1, J54.3, R126.1, U44.43
AVDD8: C191.1, J61.3, R142.1, U50.43
AVDD9: C213.1, J68.3, R158.1, U56.43
AVDD10: C235.1, J75.3, R174.1, U62.43
AVDD11: C257.1, J82.3, R190.1, U68.43
BATT_ALERT: U2.5, U5.36
BATT_ALERT1: U8.36, U9.5
BATT_ALERT2: U14.36, U15.5
BATT_ALERT3: U20.36, U21.5
BATT_ALERT4: U26.36, U27.5
BATT_ALERT5: U32.36, U33.5
BATT_ALERT6: U38.36, U39.5
BATT_ALERT7: U44.36, U45.5
BATT_ALERT8: U50.36, U51.5
BATT_ALERT9: U56.36, U57.5
BATT_ALERT10: U62.36, U63.5
BATT_ALERT11: U68.36, U69.5
BOOT: R5.2, S1.3
BOOT1: R22.2, S4.3
BOOT2: R38.2, S6.3
BOOT3: R54.2, S8.3
BOOT4: R70.2, S10.3
BOOT5: R86.2, S12.3
BOOT6: R102.2, S14.3
BOOT7: R118.2, S16.3
BOOT8: R134.2, S18.3
BOOT9: R150.2, S20.3
BOOT10: R166.2, S22.3
BOOT11: R182.2, S24.3
EN: J8.2, R16.1, U7.3
EN1: J13.2, R27.1, U11.3
EN2: J20.2, R43.1, U17.3
EN3: J27.2, R59.1, U23.3
EN4: J34.2, R75.1, U29.3
EN5: J41.2, R91.1, U35.3
EN6: J48.2, R107.1, U41.3
EN7: J55.2, R123.1, U47.3
EN8: J62.2, R139.1, U53.3
EN9: J69.2, R155.1, U59.3
EN10: J76.2, R171.1, U65.3
EN11: J83.2, R187.1, U71.3
GND: C1.2, C2.2, C3.2, C4.2, C5.1, C7.2, C8.2, C9.2, C10.2, C16.1, C17.2, C18.2, C20.2, C21.2, C22.2, C23.2, C24.2, C25.2, C26.2, C27.2, C28.2, C29.2, J1.3, J1.5, J1.9, J3.1, J4.1, J5.GND, J5.GND2, J6.CD1, J6.GND, J6.GND1, J6.GND3, J7.4, R1.2, R3.1, R4.2, R6.1, R8.1, R15.1, S1.1, S2.1, U2.1, U2.4, U2.6, U2.9, U3.2, U4.4, U5.19, U5.EPAD, U6.2, U7.2
GND1: C6.2, C11.2, C12.1, C13.1, C14.2, C15.2, C19.2, C30.2, C31.2, C32.2, C33.2, C34.2, C35.2, C36.2, C37.2, C38.2, C39.2, C40.2, C41.2, C42.2, C43.2, C44.2, J2.1, J9.1, J10.GND, J10.GND2, J11.CD1, J11.GND, J11.GND1, J11.GND3, J12.4, J14.3, J14.5, J14.9, R24.2, R25.2, R26.1, R29.1, R31.1, R32.1, S3.1, S4.1, U1.4, U8.19, U8.EPAD, U9.1, U9.4, U9.6, U9.9, U10.2, U11.2, U12.2
GND2: C45.2, C46.2, C47.1, C48.1, C49.2, C50.2, C51.2, C52.2, C53.2, C54.2, C55.2, C56.2, C57.2, C58.2, C59.2, C60.2, C61.2, C62.2, C63.2, C64.2, C65.2, C66.2, J15.1, J16.1, J17.GND, J17.GND2, J18.CD1, J18.GND, J18.GND1, J18.GND3, J19.4, J21.3, J21.5, J21.9, R40.2, R41.2, R42.1, R45.1, R47.1, R48.1, S5.1, S6.1, U13.4, U14.19, U14.EPAD, U15.1, U15.4, U15.6, U15.9, U16.2, U17.2, U18.2
GND3: C67.2, C68.2, C69.1, C70.1, C71.2, C72.2, C73.2, C74.2, C75.2, C76.2, C77.2, C78.2, C79.2, C80.2, C81.2, C82.2, C83.2, C84.2, C85.2, C86.2, C87.2, C88.2, J22.1, J23.1, J24.GND, J24.GND2, J25.CD1, J25.GND, J25.GND1, J25.GND3, J26.4, J28.3, J28.5, J28.9, R56.2, R57.2, R58.1, R61.1, R63.1, R64.1, S7.1, S8.1, U19.4, U20.19, U20.EPAD, U21.1, U21.4, U21.6, U21.9, U22.2, U23.2, U24.2
GND4: C89.2, C90.2, C91.1, C92.1, C93.2, C94.2, C95.2, C96.2, C97.2, C98.2, C99.2, C100.2, C101.2, C102.2, C103.2, C104.2, C105.2, C106.2, C107.2, C108.2, C109.2, C110.2, J29.1, J30.1, J31.GND, J31.GND2, J32.CD1, J32.GND, J32.GND1, J32.GND3, J33.4, J35.3, J35.5, J35.9, R72.2, R73.2, R74.1, R77.1, R79.1, R80.1, S9.1, S10.1, U25.4, U26.19, U26.EPAD, U27.1, U27.4, U27.6, U27.9, U28.2, U29.2, U30.2
GND5: C111.2, C112.2, C113.1, C114.1, C115.2, C116.2, C117.2, C118.2, C119.2, C120.2, C121.2, C122.2, C123.2, C124.2, C125.2, C126.2, C127.2, C128.2, C129.2, C130.2, C131.2, C132.2, J36.1, J37.1, J38.GND, J38.GND2, J39.CD1, J39.GND, J39.GND1, J39.GND3, J40.4, J42.3, J42.5, J42.9, R88.2, R89.2, R90.1, R93.1, R95.1, R96.1, S11.1, S12.1, U31.4, U32.19, U32.EPAD, U33.1, U33.4, U33.6, U33.9, U34.2, U35.2, U36.2
GND6: C133.2, C134.2, C135.1, C136.1, C137.2, C138.2, C139.2, C140.2, C141.2, C142.2, C143.2, C144.2, C145.2, C146.2, C147.2, C148.2, C149.2, C150.2, C151.2, C152.2, C153.2, C154.2, J43.1, J44.1, J45.GND, J45.GND2, J46.CD1, J46.GND, J46.GND1, J46.GND3, J47.4, J49.3, J49.5, J49.9, R104.2, R105.2, R106.1, R109.1, R111.1, R112.1, S13.1, S14.1, U37.4, U38.19, U38.EPAD, U39.1, U39.4, U39.6, U39.9, U40.2, U41.2, U42.2
GND7: C155.2, C156.2, C157.1, C158.1, C159.2, C160.2, C161.2, C162.2, C163.2, C164.2, C165.2, C166.2, C167.2, C168.2, C169.2, C170.2, C171.2, C172.2, C173.2, C174.2, C175.2, C176.2, J50.1, J51.1, J52.GND, J52.GND2, J53.CD1, J53.GND, J53.GND1, J53.GND3, J54.4, J56.3, J56.5, J56.9, R120.2, R121.2, R122.1, R125.1, R127.1, R128.1, S15.1, S16.1, U43.4, U44.19, U44.EPAD, U45.1, U45.4, U45.6, U45.9, U46.2, U47.2, U48.2
GND8: C177.2, C178.2, C179.1, C180.1, C181.2, C182.2, C183.2, C184.2, C185.2, C186.2, C187.2, C188.2, C189.2, C190.2, C191.2, C192.2, C193.2, C194.2, C195.2, C196.2, C197.2, C198.2, J57.1, J58.1, J59.GND, J59.GND2, J60.CD1, J60.GND, J60.GND1, J60.GND3, J61.4, J63.3, J63.5, J63.9, R136.2, R137.2, R138.1, R141.1, R143.1, R144.1, S17.1, S18.1, U49.4, U50.19, U50.EPAD, U51.1, U51.4, U51.6, U51.9, U52.2, U53.2, U54.2
GND9: C199.2, C200.2, C201.1, C202.1, C203.2, C204.2, C205.2, C206.2, C207.2, C208.2, C209.2, C210.2, C211.2, C212.2, C213.2, C214.2, C215.2, C216.2, C217.2, C218.2, C219.2, C220.2, J64.1, J65.1, J66.GND, J66.GND2, J67.CD1, J67.GND, J67.GND1, J67.GND3, J68.4, J70.3, J70.5, J70.9, R152.2, R153.2, R154.1, R157.1, R159.1, R160.1, S19.1, S20.1, U55.4, U56.19, U56.EPAD, U57.1, U57.4, U57.6, U57.9, U58.2, U59.2, U60.2
GND10: C221.2, C222.2, C223.1, C224.1, C225.2, C226.2, C227.2, C228.2, C229.2, C230.2, C231.2, C232.2, C233.2, C234.2, C235.2, C236.2, C237.2, C238.2, C239.2, C240.2, C241.2, C242.2, J71.1, J72.1, J73.GND, J73.GND2, J74.CD1, J74.GND, J74.GND1, J74.GND3, J75.4, J77.3, J77.5, J77.9, R168.2, R169.2, R170.1, R173.1, R175.1, R176.1, S21.1, S22.1, U61.4, U62.19, U62.EPAD, U63.1, U63.4, U63.6, U63.9, U64.2, U65.2, U66.2
GND11: C243.2, C244.2, C245.1, C246.1, C247.2, C248.2, C249.2, C250.2, C251.2, C252.2, C253.2, C254.2, C255.2, C256.2, C257.2, C258.2, C259.2, C260.2, C261.2, C262.2, C263.2, C264.2, J78.1, J79.1, J80.GND, J80.GND2, J81.CD1, J81.GND, J81.GND1, J81.GND3, J82.4, J84.3, J84.5, J84.9, R184.2, R185.2, R186.1, R189.1, R191.1, R192.1, S23.1, S24.1, U67.4, U68.19, U68.EPAD, U69.1, U69.4, U69.6, U69.9, U70.2, U71.2, U72.2
GPIO1: J13.4, U8.27
GPIO2: J13.5, U8.28
GPIO3: J13.6, U8.29
GPIO4: J13.7, U8.30
GPIO5: J13.8, U8.31
GPIO6: J13.9, U8.32
GPIO7: J13.10, U8.34
GPIO8: J20.4, U14.27
GPIO9: J20.5, U14.28
GPIO10: J20.6, U14.29
GPIO11: J20.7, U14.30
GPIO12: J20.8, U14.31
GPIO13: J20.9, U14.32
GPIO14: J20.10, U14.34
GPIO15: J27.4, U20.27
GPIO16: J8.4, U5.27
GPIO17: J8.5, U5.28
GPIO18: J8.6, U5.29
GPIO19: J8.7, U5.30
GPIO20: J8.8, U5.31
GPIO21: J8.9, U5.32
GPIO22: J8.10, U5.34
GPIO23: J27.5, U20.28
GPIO24: J27.6, U20.29
GPIO25: J27.7, U20.30
GPIO26: J27.8, U20.31
GPIO27: J27.9, U20.32
GPIO28: J27.10, U20.34
GPIO29: J34.4, U26.27
GPIO30: J34.5, U26.28
GPIO31: J34.6, U26.29
GPIO32: J34.7, U26.30
GPIO33: J34.8, U26.31
GPIO34: J34.9, U26.32
GPIO35: J34.10, U26.34
GPIO36: J41.4, U32.27
GPIO37: J41.5, U32.28
GPIO38: J41.6, U32.29
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

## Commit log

2020-11-20 Airwire in progress
    [RP2040_Thing_Plus.brd, RP2040_Thing_Plus.sch]
2020-11-23 airwire corrections
    [RP2040_Thing_Plus.brd, RP2040_Thing_Plus.sch]
2020-12-01 v01 review
    [RP2040_Thing_Plus.brd, RP2040_Thing_Plus.sch]
2020-12-02 Review Changes
    - Add "Pi Thing Plus RP2040" silk
    - Align LEDs
    - Change LED label style
    - Flip bottom silk labels
    - Add GND vias
    - Beef up power traces
    - Add thermal vias under RP2040
    - Straighten trace on ADC0
    - Add SDA/SCL Labels to bottom silk
    - Add PWR LED
    - Move QSPI resistors to make room for silk
    Passes micromod.dru (overlap errors for jumper footprint + thermal vias)
    [RP2040_Thing_Plus.brd, RP2040_Thing_Plus.sch]
2020-12-02 Move silk on LiPo connector. Add ignore. Remove backups.
    [RP2040_Thing_Plus.brd]
2020-12-02 Run lib update on schematic. Compress schematic wires. Push production files.
    [RP2040_Thing_Plus-Panel.GBL, RP2040_Thing_Plus-Panel.GBO, RP2040_Thing_Plus-Panel.GBP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]
2020-12-30 Change res on charger to 2k
    [RP2040_Thing_Plus.brd, RP2040_Thing_Plus.sch]
2020-12-30 Correct product name silk
    [RP2040_Thing_Plus.brd]
2021-01-07 Panel with 2k charge resistor
    [RP2040_Thing_Plus-Panel.GBL, RP2040_Thing_Plus-Panel.GBO, RP2040_Thing_Plus-Panel.GBP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]
2021-01-14 Add TPs to SWD. Connect reset. v11.
    [RP2040_Thing_Plus.brd, RP2040_Thing_Plus.sch]
2021-01-14 Panelize v11
    [RP2040_Thing_Plus-Panel.GBL, RP2040_Thing_Plus-Panel.GBO, RP2040_Thing_Plus-Panel.GBP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]
2021-01-15 Add RP2040 Logo
    [RP2040_Thing_Plus-Panel.GBL, RP2040_Thing_Plus-Panel.GBO, RP2040_Thing_Plus-Panel.GBP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]
2021-01-15 Update RP2040 Logo
    [RP2040_Thing_Plus-Panel.brd, RP2040_Thing_Plus.brd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]

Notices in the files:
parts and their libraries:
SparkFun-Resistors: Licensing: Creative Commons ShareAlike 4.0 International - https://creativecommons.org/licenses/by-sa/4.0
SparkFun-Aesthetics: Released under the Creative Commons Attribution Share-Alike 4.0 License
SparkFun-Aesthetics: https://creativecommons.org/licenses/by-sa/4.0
